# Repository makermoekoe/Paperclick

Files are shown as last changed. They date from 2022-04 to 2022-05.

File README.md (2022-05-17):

# Paperclick

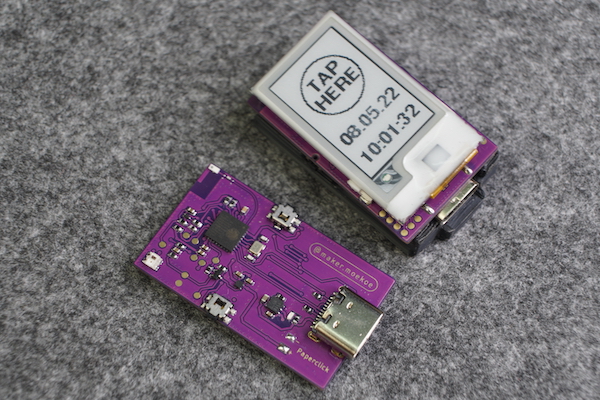
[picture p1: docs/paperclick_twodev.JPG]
</a>

Paperclick is a simple device which combines a [Picoclick-C3T](https://github.com/makermoekoe/Picoclick-C3) with the smallest EPaper display I found in the internet: [a 1.02" 128x80 pixels EPD](https://www.waveshare.com/wiki/1.02inch_e-paper_Module). The initial task was to create a simple activity tracker which updates the EPaper display with the current date and time once the display is pressed (actually it is not the display sensing the press, it's a button behind the display). The device gets the time from an NTP server over WiFi. Additionally the device can update an online service with the date/time the Paperclick was pressed.

Paperclick is based on the single core ESP32-C3 processor which is used in the Picoclick C3T as well. Furthermore it comes with an optimized battery monitoring which brings the complete device down to around 200nA current consumption in idle state.
The latching circuit is optimized as well - it now doesn't use a GPIO of the MCU as a latch like it was done before, it uses the power supply of the embedded flash. Once the ESP32 enters deepsleep mode, that voltage supply will be pulled low to save a bit of power. This triggers the latch and the device will be disabled. And the best feature with this is that we don't have to struggle with the initial timings (boot speed up) like it was necessary with the [Picoclick-C3T](https://github.com/makermoekoe/Picoclick-C3) in its first version. The above mentioned power supply pin is immediately high once the MCU gets power (~3ms compared to minimal 60ms with using a GPIO). This makes it possible to use the Arduino framework without any restrictions!

## Features

- ESP32-C3 MCU with chip antenna
- 1.02" 128x80 pixel Epaper display
- Onboard battery charger
- Optimized battery capacity estimation
- Simple One-Button user interface (Two optional buttons available)
- WS2812 user LED
- LiPo battery charger with indicator LED

The [Youtube video](https://www.youtube.com/watch?v=tOb_UypiWvQ) shows the assembly and soldering process, explains how the battery monitoring works and shows this little thing in action.

## Battery monitoring

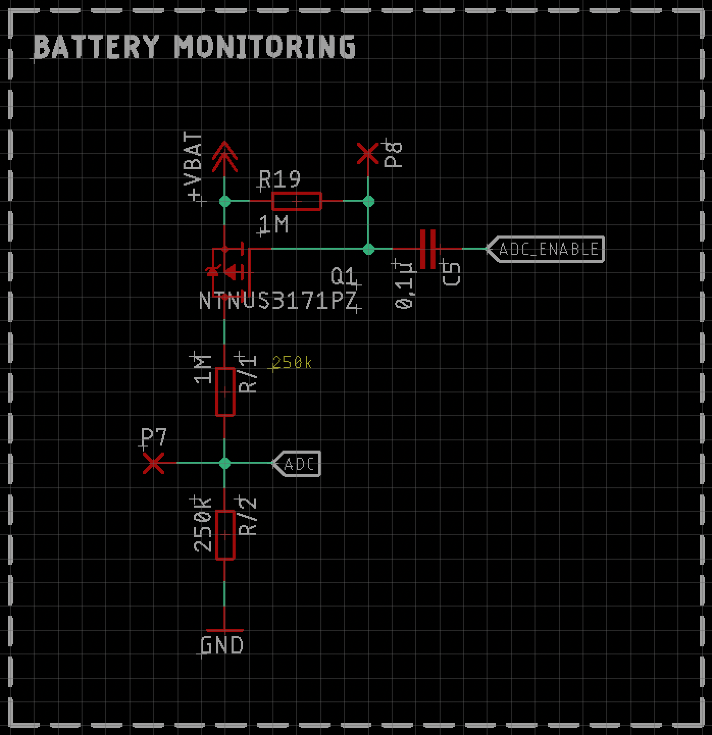
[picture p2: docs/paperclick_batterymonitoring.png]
</a>

Till now I have estimated the battery capacity with a simple voltage divider between VBAT and GND and an analog input of the MCU to read the voltage. This will draw current all the time, even if the device is not activated.

```
I = V / R = 4V / (1MΩ + 250kΩ) = 3,2µA
I = V / R = 4V / (250kΩ + 250kΩ) = 8µA
```

In order to save these few µA of current, I searched for other solution which lead me to [this](https://jeelabs.org/2013/05/18/zero-power-measurement-part-2/index.html#comments) article by Jean-Claude Wippler, where he additionally used a mosfet, a resistor and a capacitor to create something like a one-shot trigger for the voltage divider.

After some test with a Picoclick and my scope, that solution seems to be a very cool and interesting one. Paperclick is the first board where I tried this circuit, that's why there are so many measurement test points.

## Power consumption

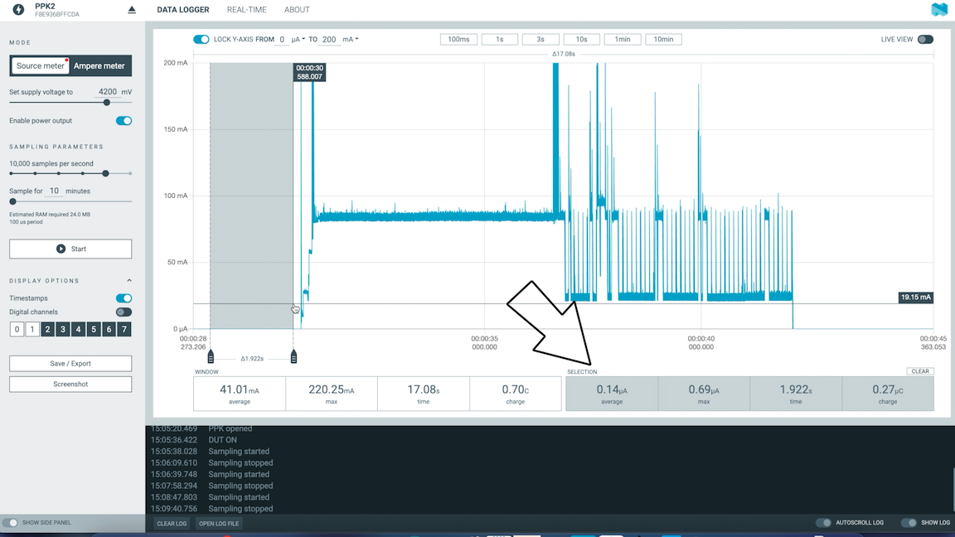
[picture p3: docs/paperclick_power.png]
</a>

- 82mA in average while WiFi connecting/transmitting and updating the ePaper display
- 38mA in average with WiFi disabled and updating the ePaper display
- 140nA in average in idle state

## Assembled devive

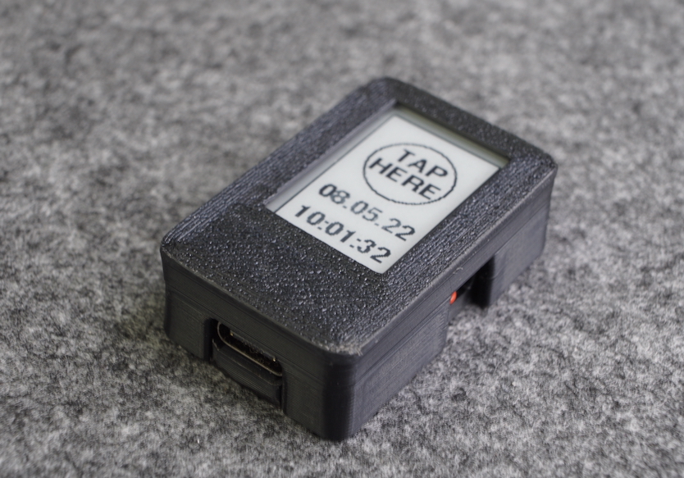
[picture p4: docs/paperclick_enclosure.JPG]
</a>

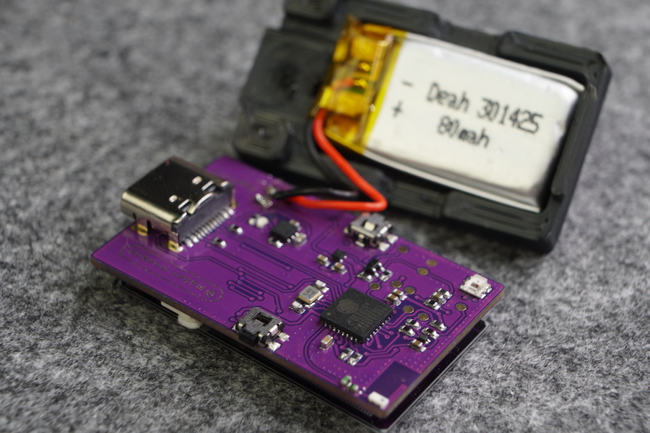
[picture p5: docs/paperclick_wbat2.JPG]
</a>

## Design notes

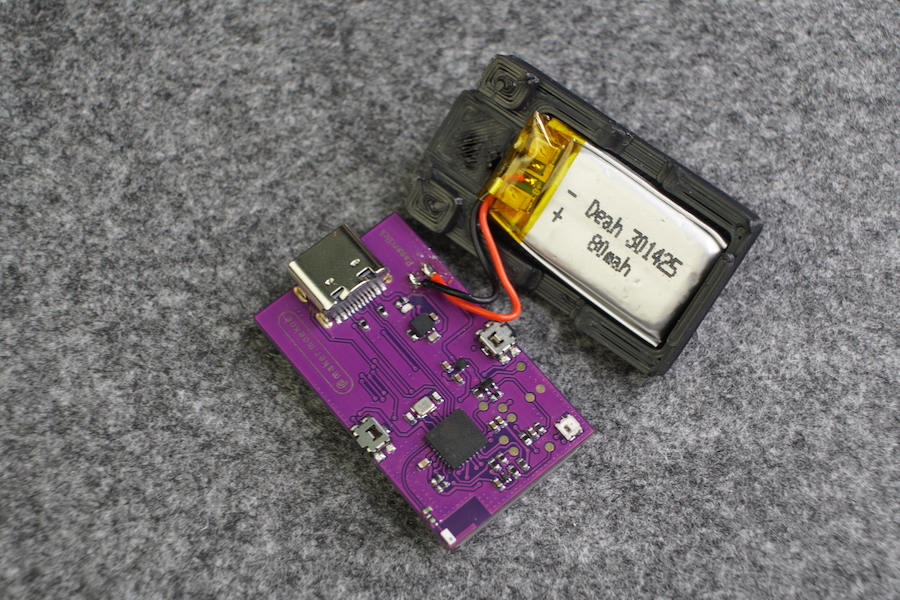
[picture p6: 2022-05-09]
docs/paperclick_wbat.JPG

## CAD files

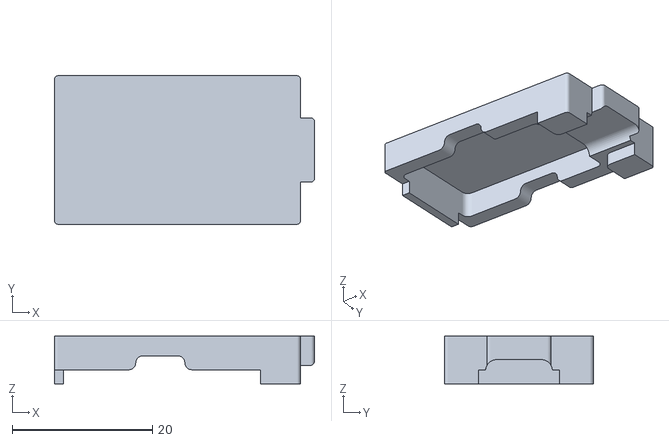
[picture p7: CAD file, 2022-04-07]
case/paperclick_bot.stl
37.1 x 21.2 x 6.80

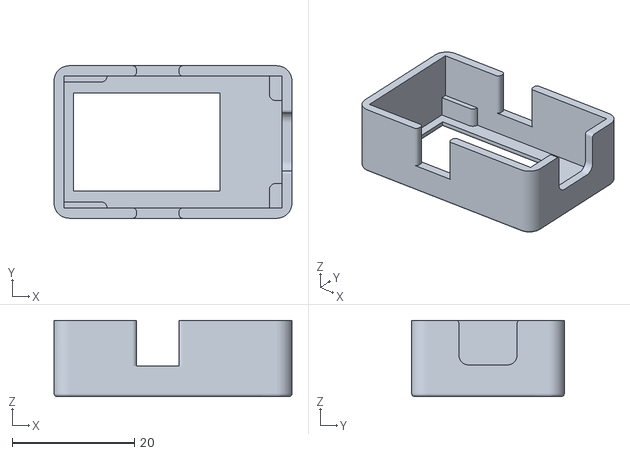
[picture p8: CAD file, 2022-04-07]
case/paperclick_top.stl
39.0 x 25.0 x 12.5

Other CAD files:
case/paperclick_top_no_btns.stl

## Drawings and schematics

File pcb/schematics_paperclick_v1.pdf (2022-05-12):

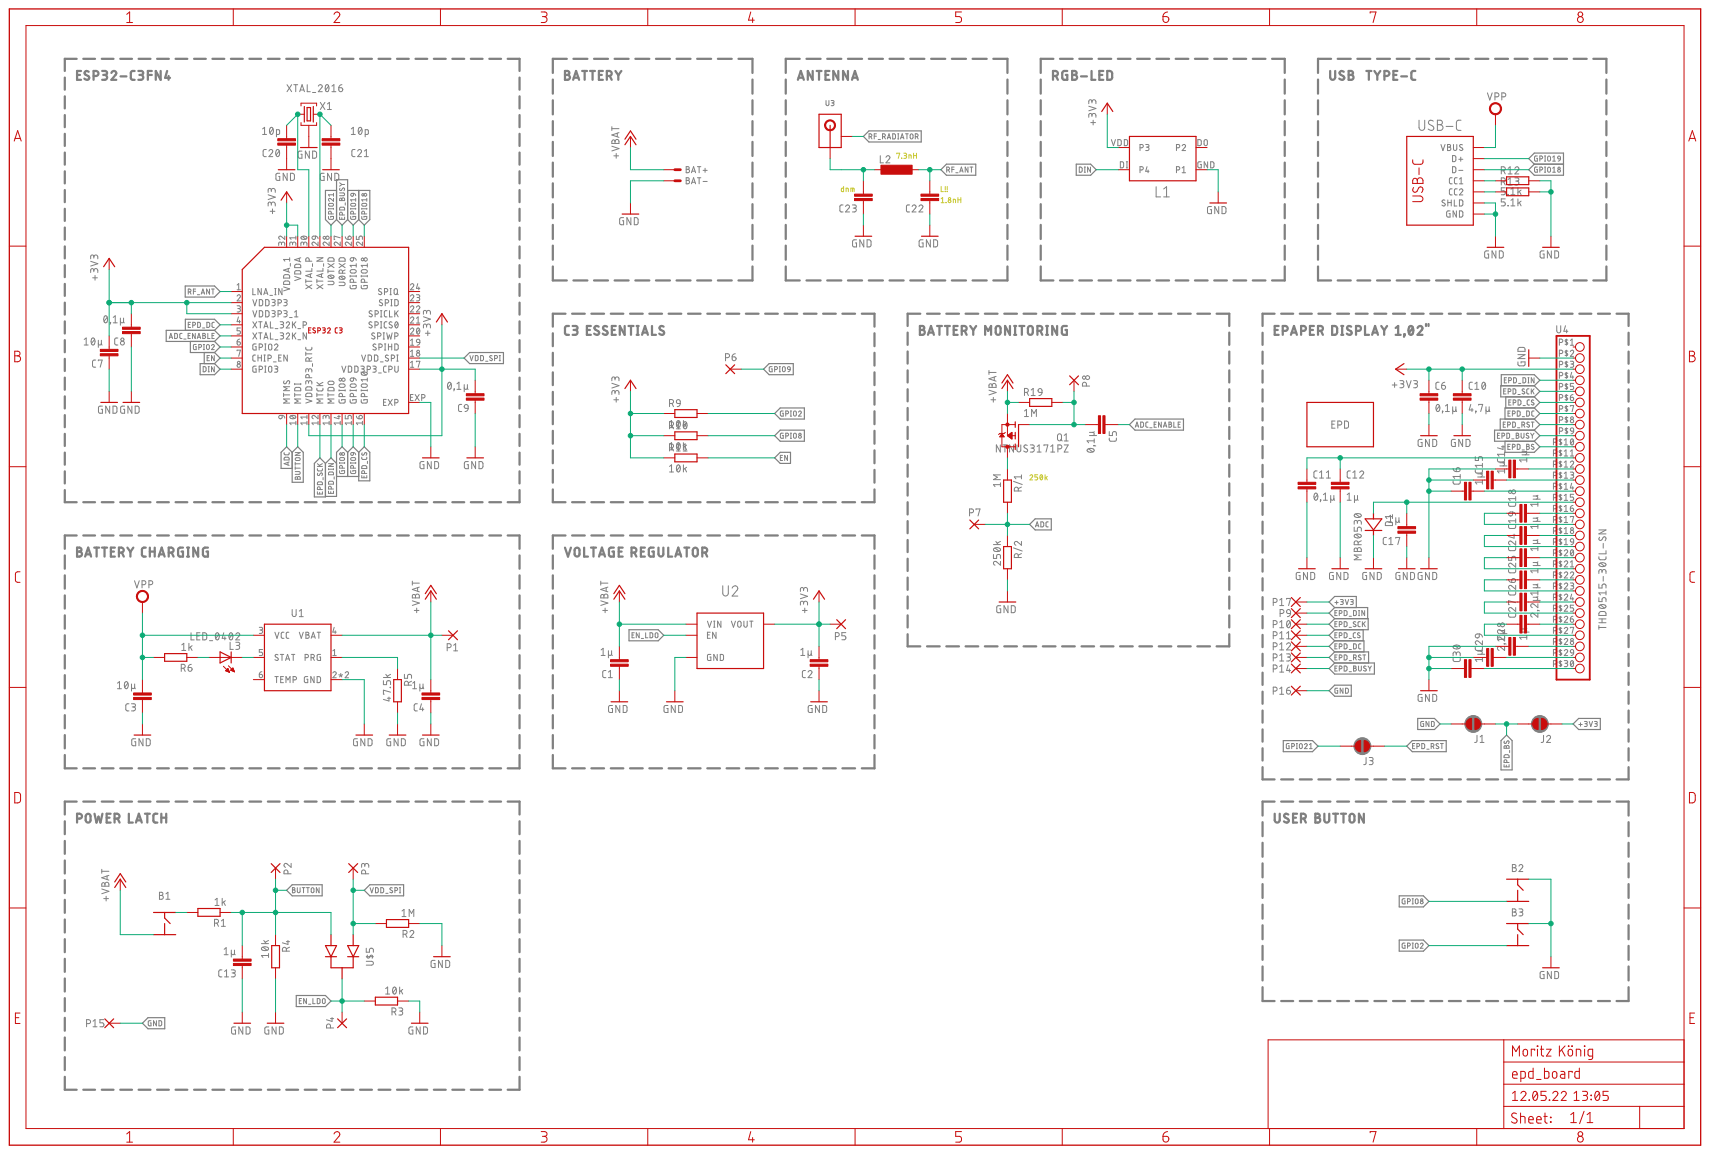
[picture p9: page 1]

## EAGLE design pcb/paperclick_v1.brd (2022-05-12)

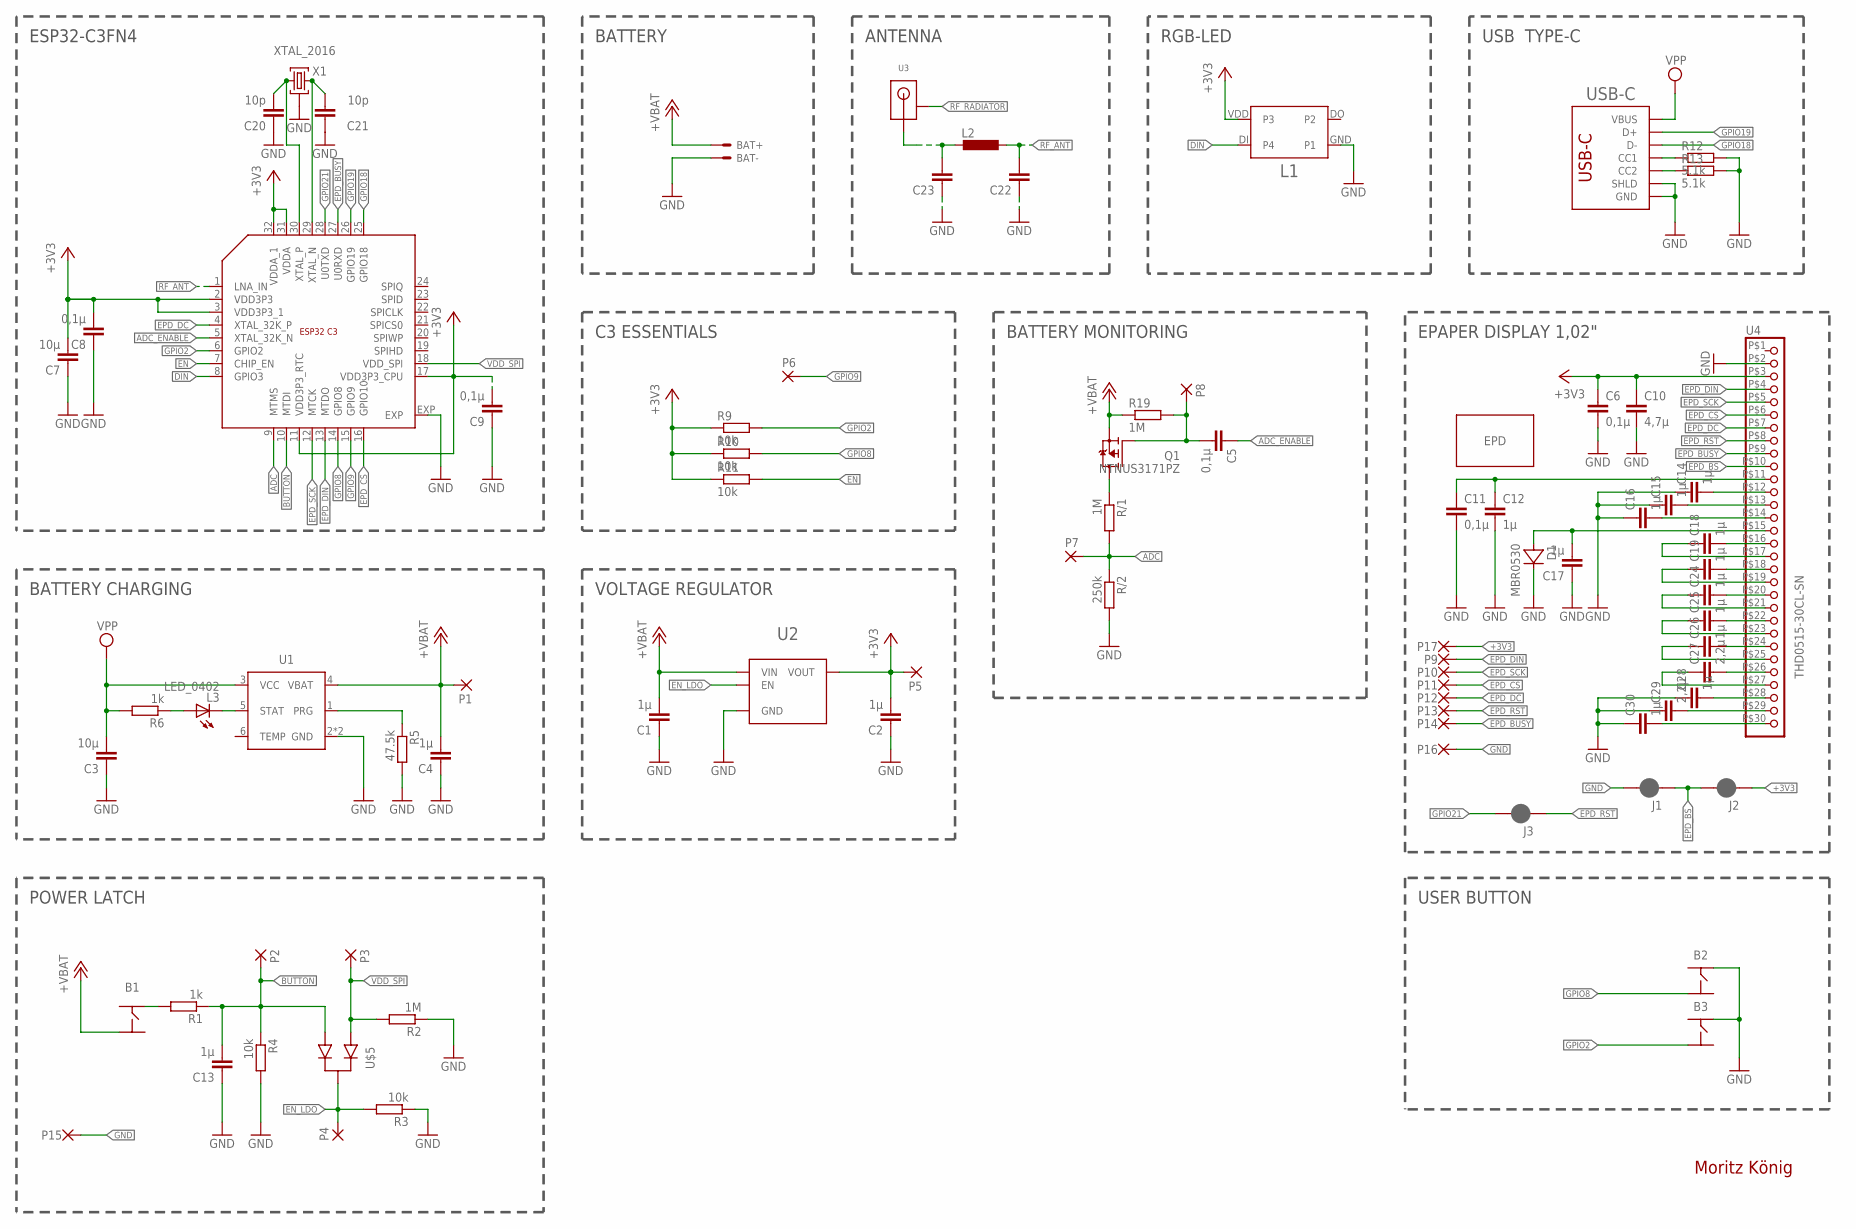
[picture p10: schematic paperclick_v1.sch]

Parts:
B1: BUTTON_4PIN_TS-1070A; BUTTON_WHITE_SMD
B2, B3: PTS840ESDGMSMTRLFS
BAT+: TP/SP-1.5X1.0; SOLDERPAD_1.5X1.0
BAT-: TP/SP-1.5X1.0; SOLDERPAD_1.5X1.0
C1, C2, C4, C12, C13, C14, C15, C16, C17, C18, C19, C24, C25, C26, C28, C30: 1µ; C0402_S
C3, C7: 10µ; C0402_S
C5, C6, C8, C9, C11: 0,1µ; C0402_S
C10: 4,7µ; C0402_S
C20, C21: 10p; C0402_S
C22, C23: C0201
C27, C29: 2,2µ; C0402_S
D1: MBR0530; SOD123
ESP1: ESP32_C3_QFN32; QFN32
J1, J2, J3: SMT_JUMPER_2_NC_PASTE; JUMPER_SMALL
L1: WS2812_2020
L2: L0201
L3: LED_0402; CHIPLED_0402
P1, P2, P3, P4, P5, P6, P7, P8, P9, P10, P11, P12, P13, P14, P15, P16, P17: SMD-R1
Q1: NTNUS3171PZ; SOT1123
R1, R6: 1k; R0402
R2, R19: 1M; R0402
R3, R4, R9, R10, R11: 10k; R0402
R5: 47.5k; R0402
R12, R13: 5.1k; R0402
R/1: 1M; R0402
R/2: 250k; R0402
U1: WS4518D; DFN-6
U2: MIC5504; TDFN4
U3: ANT016008LCS2442MA2
U4: THD0515-30CL-SN
U$2: EPD-102-30PIN-TW
U$5: DAN222; SOT523
USB-C: USB_C_C393939; USBC_C393939
X1: XTAL_2016

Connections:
+3V3: C2.P$2 (2), C6.P$1 (1), C7.P$2 (2), C8.P$2 (2), C9.P$2 (2), C10.P$1 (1), ESP1.2 (VDD3P3), ESP1.3 (VDD3P3_1), ESP1.11 (VDD3P3_RTC), ESP1.17 (VDD3P3_CPU), ESP1.31 (VDDA), ESP1.32 (VDDA_1), J2.P$1 (1), L1.VDD (P3), P5.P$1, P17.P$1, R9.1, R10.1, R11.1, U2.P1 (VOUT), U4.P$3 (3)
+VBAT: B1.P$2 (3), BAT+.1, C1.P$2 (2), C4.P$2 (2), P1.P$1, Q1.2 (S), R19.1, U1.4 (VBAT), U2.P4 (VIN)
ADC: ESP1.9 (MTMS), P7.P$1, R/1.2, R/2.1
ADC_ENABLE: C5.P$1 (1), ESP1.5 (XTAL_32K_N)
BUTTON: C13.P$2 (2), ESP1.10 (MTDI), P2.P$1, R1.1, R4.1, U$5.2
DIN: ESP1.8 (GPIO3), L1.DI (P4)
EN: ESP1.7 (CHIP_EN), R11.2
EN_LDO: P4.P$1, R3.2, U2.P3 (EN), U$5.3
EPD_BS: J1.P$1 (1), J2.P$2 (2), U4.P$10 (10)
EPD_BUSY: ESP1.27 (U0RXD), P14.P$1, U4.P$9 (9)
EPD_CS: ESP1.16 (GPIO10), P11.P$1, U4.P$6 (6)
EPD_DC: ESP1.4 (XTAL_32K_P), P12.P$1, U4.P$7 (7)
EPD_DIN: ESP1.13 (MTDO), P9.P$1, U4.P$4 (4)
EPD_RST: J3.P$1 (1), P13.P$1, U4.P$8 (8)
EPD_SCK: ESP1.12 (MTCK), P10.P$1, U4.P$5 (5)
GND: B2.2, B3.2, BAT-.1, C1.P$1 (1), C2.P$1 (1), C3.P$1 (1), C4.P$1 (1), C6.P$2 (2), C7.P$1 (1), C8.P$1 (1), C9.P$1 (1), C10.P$2 (2), C11.P$2 (2), C12.P$2 (2), C13.P$1 (1), C14.P$1 (1), C15.P$1 (1), C16.P$1 (1), C17.P$1 (1), C20.P$1 (1), C21.P$1 (1), C22.P$1 (1), C23.P$1 (1), C28.P$1 (1), C29.P$1 (1), C30.P$1 (1), D1.P$2 (C), ESP1.EXP, J1.P$2 (2), L1.GND (P1), P15.P$1, P16.P$1, R2.1, R3.1, R4.2, R5.2, R12.2, R13.2, R/2.2, U1.2 (GND), U1.EXP (GND), U2.EXP (GND), U2.P2 (GND), U4.P$2 (2), USB-C.A1B12 (GND), USB-C.B1A12 (GND), USB-C.S1 (SHLD), USB-C.S2 (SHLD), USB-C.S3 (SHLD), USB-C.S4 (SHLD), X1.P2 (G), X1.P4 (G)
GPIO2: B3.3, ESP1.6 (GPIO2), R9.2
GPIO8: B2.3, ESP1.14 (GPIO8), R10.2
GPIO9: ESP1.15 (GPIO9), P6.P$1
GPIO18: ESP1.25 (GPIO18), USB-C.A7 (D-), USB-C.B7 (D-)
GPIO19: ESP1.26 (GPIO19), USB-C.A6 (D+), USB-C.B6 (D+)
GPIO21: ESP1.28 (U0TXD), J3.P$2 (2)
unnamed: B1.P$4 (2), R1.2
unnamed: L3.P$2 (A), R6.1
unnamed: L3.P$1 (C), U1.5 (STAT)
unnamed: Q1.3 (D), R/1.1
unnamed: C23.P$2 (2), L2.P$2 (2), U3.3 (ANT)
unnamed: C5.P$2 (2), P8.P$1, Q1.1 (G), R19.2
unnamed: R13.1, USB-C.B5 (CC2)
unnamed: C11.P$1 (1), C12.P$1 (1), U4.P$11 (11)
unnamed: C14.P$2 (2), U4.P$12 (12)
unnamed: C15.P$2 (2), U4.P$13 (13)
unnamed: C16.P$2 (2), U4.P$14 (14)
unnamed: R5.1, U1.1 (PRG)
unnamed: C17.P$2 (2), D1.P$1 (A), U4.P$15 (15)
unnamed: R12.1, USB-C.A5 (CC1)
unnamed: C20.P$2 (2), ESP1.30 (XTAL_P), X1.P1 (1)
unnamed: C21.P$2 (2), ESP1.29 (XTAL_N), X1.P3 (2)
unnamed: C18.P$2 (2), U4.P$16 (16)
unnamed: C18.P$1 (1), U4.P$17 (17)
unnamed: C19.P$2 (2), U4.P$18 (18)
unnamed: C19.P$1 (1), U4.P$19 (19)
unnamed: C24.P$2 (2), U4.P$20 (20)
unnamed: C24.P$1 (1), U4.P$21 (21)
unnamed: C25.P$2 (2), U4.P$22 (22)
unnamed: C25.P$1 (1), U4.P$23 (23)
unnamed: C26.P$2 (2), U4.P$24 (24)
unnamed: C26.P$1 (1), U4.P$25 (25)
unnamed: C27.P$2 (2), U4.P$26 (26)
unnamed: C27.P$1 (1), U4.P$27 (27)
unnamed: C28.P$2 (2), U4.P$28 (28)
unnamed: C29.P$2 (2), U4.P$29 (29)
unnamed: C30.P$2 (2), U4.P$30 (30)
RF_ANT: C22.P$2 (2), ESP1.1 (LNA_IN), L2.P$1 (1)
RF_RADIATOR: U3.1 (GND)
VDD_SPI: ESP1.18 (VDD_SPI), P3.P$1, R2.2, U$5.1
VPP: C3.P$2 (2), R6.2, U1.3 (VCC), USB-C.A4B9 (VBUS), USB-C.B4A9 (VBUS)

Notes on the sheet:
Moritz König
BATTERY MONITORING
ANTENNA
USB TYPE-C
VOLTAGE REGULATOR
RGB-LED
POWER LATCH
C3 ESSENTIALS
BATTERY CHARGING
ESP32-C3FN4
BATTERY
EPAPER DISPLAY 1,02"
USER BUTTON

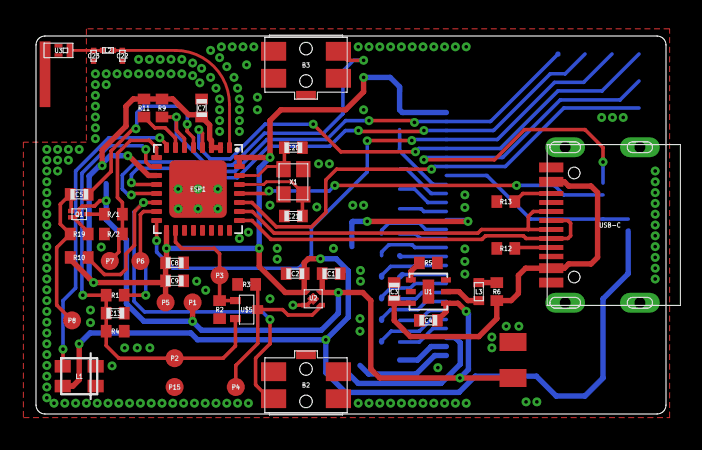
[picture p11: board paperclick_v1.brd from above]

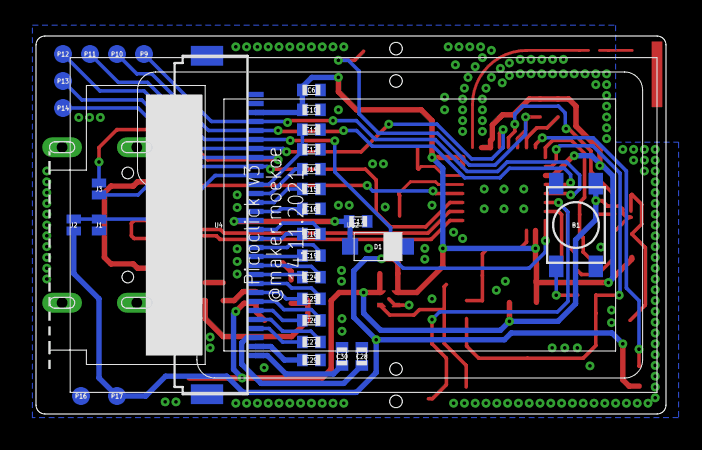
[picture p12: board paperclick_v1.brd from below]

Board: 2 copper layers, 35.0 x 21.0 mm, 83 parts (32 on the bottom side), 56 nets.

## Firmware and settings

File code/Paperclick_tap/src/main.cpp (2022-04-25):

#include <Arduino.h>
#include <Wire.h>

#include <WiFi.h>
#include <TimeLib.h>
#include <WiFiUdp.h>


const char* ssid     = "WLAN-VTXKHJ";
const char* password = "HOU08BAKLK32a";

static const char ntpServerName[] = "us.pool.ntp.org";
const int timeZone = 2;     // Central European Time

WiFiUDP Udp;
unsigned int localPort = 8888;  // local port to listen for UDP packets


// Hardware Definitions
#define SPI_EPD_CLK     6
#define SPI_EPD_MOSI    7
#define SPI_EPD_MISO    -1
#define SPI_EPD_CS      10
#define SPI_EPD_BUSY    20
#define SPI_EPD_RST     21
#define SPI_EPD_DC      0

#define ADC_ENABLE_PIN  1
#define WS2812_PIN      3
#define ADC_PIN         4
#define BUTTON1_PIN     5
#define BUTTON2_PIN     8
#define BUTTON3_PIN     2


#include <GxEPD2_BW.h>
#include <GxEPD2_3C.h>
#include <Fonts/FreeSansBold9pt7b.h>
#include "GxEPD2_display_selection_new_style.h"


/*-------- NTP code ----------*/

const int NTP_PACKET_SIZE = 48; // NTP time is in the first 48 bytes of message
byte packetBuffer[NTP_PACKET_SIZE]; //buffer to hold incoming & outgoing packets

// send an NTP request to the time server at the given address
void sendNTPpacket(IPAddress &address)
{
  // set all bytes in the buffer to 0
  memset(packetBuffer, 0, NTP_PACKET_SIZE);
  // Initialize values needed to form NTP request
  // (see URL above for details on the packets)
  packetBuffer[0] = 0b11100011;   // LI, Version, Mode
  packetBuffer[1] = 0;     // Stratum, or type of clock
  packetBuffer[2] = 6;     // Polling Interval
  packetBuffer[3] = 0xEC;  // Peer Clock Precision
  // 8 bytes of zero for Root Delay & Root Dispersion
  packetBuffer[12] = 49;
  packetBuffer[13] = 0x4E;
  packetBuffer[14] = 49;
  packetBuffer[15] = 52;
  // all NTP fields have been given values, now
  // you can send a packet requesting a timestamp:
  Udp.beginPacket(address, 123); //NTP requests are to port 123
  Udp.write(packetBuffer, NTP_PACKET_SIZE);
  Udp.endPacket();
}

time_t getNtpTime(){
  IPAddress ntpServerIP; // NTP server's ip address

  while (Udp.parsePacket() > 0) ; // discard any previously received packets
  WiFi.hostByName(ntpServerName, ntpServerIP);
  sendNTPpacket(ntpServerIP);
  uint32_t beginWait = millis();
  while (millis() - beginWait < 1500) {
    int size = Udp.parsePacket();
    if (size >= NTP_PACKET_SIZE) {
      Udp.read(packetBuffer, NTP_PACKET_SIZE);  // read packet into the buffer
      unsigned long secsSince1900;
      // convert four bytes starting at location 40 to a long integer
      secsSince1900 =  (unsigned long)packetBuffer[40] << 24;
      secsSince1900 |= (unsigned long)packetBuffer[41] << 16;
      secsSince1900 |= (unsigned long)packetBuffer[42] << 8;
      secsSince1900 |= (unsigned long)packetBuffer[43];
      return secsSince1900 - 2208988800UL + timeZone * SECS_PER_HOUR;
    }
  }
  return 0;
}

String get_formatted_time(){
  String str = "";
  if(hour() < 10) str += "0";
  str += String(hour()) + ":";
  if(minute() < 10) str += "0";
  str += String(minute()) + ":";
  if(second() < 10) str += "0";
  str += String(second());
  return str;
}

String get_formatted_date(){
  String str = "";
  if(day() < 10) str += "0";
  str += String(day()) + ".";
  if(month() < 10) str += "0";
  str += String(month()) + ".";
  str += String(year()-2000);
  return str;
}



struct fonts {
  const GFXfont* font;
  int width;
  int height;
};

fonts font_xl = {&FreeSansBold9pt7b, 9, 19};
// fonts font_m = {u8g2_font_profont17_mf, 9, 11};



struct partial_box {
  int left, top, width, height;

  void clear(bool black){
    display.setPartialWindow(left, top, width, height);
    display.firstPage();
    do{
      if(black) display.fillRect(left, top, width, height, GxEPD_BLACK);
      else display.fillRect(left, top, width, height, GxEPD_WHITE);
    }
    while (display.nextPage());
  }

  void print_text(String str, fonts f) {
    display.setPartialWindow(left, top, width, height);
    display.setFont(f.font);
    display.setTextColor(GxEPD_BLACK);

    int16_t tbx, tby; uint16_t tbw, tbh;
    display.getTextBounds(str, left, top, &tbx, &tby, &tbw, &tbh);
    uint16_t x = (left + width/2 - tbw / 2 - 1);
    display.getTextBounds(str, left, top, &tbx, &tby, &tbw, &tbh);
    uint16_t y = top + height/2 + tbh/2 - 1;

    display.firstPage();
    do{
      display.fillRect(left, top, width, height, GxEPD_WHITE);
      display.setCursor(x, y);
      display.print(str);
    }
    while (display.nextPage());
  }

  void print_tap_circle() {
    display.setPartialWindow(left, top, width, height);
    display.setFont(font_xl.font);
    display.setTextColor(GxEPD_BLACK);
    
    int16_t tbx, tby; uint16_t tbw, tbh;
    display.getTextBounds("TAP", left, top, &tbx, &tby, &tbw, &tbh);
    uint16_t x1 = (left + width/2 - tbw / 2 - 1);
    display.getTextBounds("HERE", left, top, &tbx, &tby, &tbw, &tbh);
    uint16_t x2 = (left + width/2 - tbw / 2 - 1);
    display.getTextBounds("TAP", left, top, &tbx, &tby, &tbw, &tbh);
    uint16_t y = top + height/2 + tbh/2 - 1;

    display.firstPage();
    do{
      display.fillRect(left, top, width, height, GxEPD_WHITE);
      display.drawCircle(left+width/2, top+height/2, width/2-1, GxEPD_BLACK);
      display.drawCircle(left+width/2, top+height/2, width/2-2, GxEPD_BLACK);
      display.setCursor(x1, y-10);
      display.print("TAP");
      display.setCursor(x2, y+7);
      display.print("HERE");
    }
    while (display.nextPage());
  }
};

// Initializing the boxes
partial_box main_circle = {10, 10, display.width() - 20, display.width() - 20};
partial_box main_text_1 = {5, main_circle.top + main_circle.height + 5, display.width() - 10, 25};
partial_box main_text_2 = {5, main_text_1.top + main_text_1.height, display.width() - 10, 25};


float get_battery_voltage(){
  digitalWrite(ADC_ENABLE_PIN, LOW);
  delay(2);
  int sum = 0;
  for(int i=0; i<1000; i++){
    sum = sum + analogRead(ADC_PIN);
  }
  int result = sum/1000;
  return float(result) * (1.437);
}


void setup(){

  pinMode(BUTTON1_PIN, INPUT);
  pinMode(BUTTON2_PIN, INPUT);
  pinMode(BUTTON3_PIN, INPUT);
  pinMode(ADC_ENABLE_PIN, OUTPUT);
  pinMode(ADC_PIN, INPUT);
  analogReadResolution(12);

  digitalWrite(ADC_ENABLE_PIN, HIGH);

  SPI.end(); // release standard SPI pins, e.g. SCK(18), MISO(19), MOSI(23), SS(5)
  SPI.begin(SPI_EPD_CLK, SPI_EPD_MISO, SPI_EPD_MOSI, SPI_EPD_CS); // map and init SPI pins SCK(13), MISO(12), MOSI(14), SS(15)
  display.init(0UL, true);
  display.setRotation(4);
  display.setFont(font_xl.font);
  display.setTextColor(GxEPD_BLACK);
  // display.hibernate();

  // main_circle.clear(false);

  const char hello_str[] = "Hello!";
  const char connecting_str[] = "Wifi...";
  main_text_1.print_text(hello_str, font_xl);
  delay(500);
  main_text_2.print_text(connecting_str, font_xl);


  WiFi.mode(WIFI_STA);
  WiFi.begin(ssid, password);

  while (WiFi.status() != WL_CONNECTED && millis() < 20000) {
    delay(500);
    printf(".\r\n");
  }
  printf(".\r\n");

  if(WiFi.status() == WL_CONNECTED){
    Udp.begin(localPort);

    setSyncProvider(getNtpTime);
    setSyncInterval(300);

    now();

    main_text_1.print_text(get_formatted_date(), font_xl);
    main_text_2.print_text(get_formatted_time(), font_xl);
  }
  else{
    printf("unable to connect\r\n");
    main_text_1.print_text("unable to connect", font_xl);
  }

  delay(1000);

  // display.fillScreen(GxEPD_WHITE);
  // display.display(false);

  main_circle.print_tap_circle();

  esp_sleep_enable_timer_wakeup(5000000);
  esp_deep_sleep_start();
}

time_t prevDisplay = 0;


void loop() {
  if (timeStatus() != timeNotSet) {
    if (now() != prevDisplay) { //update the display only if time has changed
      prevDisplay = now();
      printf("%s \t %s \r\n", get_formatted_date(), get_formatted_time());
    }
  }
}

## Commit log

2022-03-03 added pcb files
    [epd_board.brd, epd_board.sch]
2022-04-07 added first version case
    [paperclick_bot.stl, paperclick_top.stl, paperclick_top_no_btns.stl]
2022-05-08 updated schematics and docs
    [epd_board.brd, epd_board.sch]
2022-05-08 added power consumption to docs
    [paperclick_v1.brd, paperclick_v1.sch]
2022-05-12 updated schematics with correct values for the matching network
    [paperclick_v1.brd, paperclick_v1.sch]
